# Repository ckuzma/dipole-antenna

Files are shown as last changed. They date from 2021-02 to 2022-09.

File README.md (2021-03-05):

# dipole-antenna
A 3D printed antenna for dual-band (2-meter / 70-centimeter) use.

> NOTE: This documentation is a work-in progress.  Part names, descriptions, and photographs are all subject to change.

## Description
- As designed:
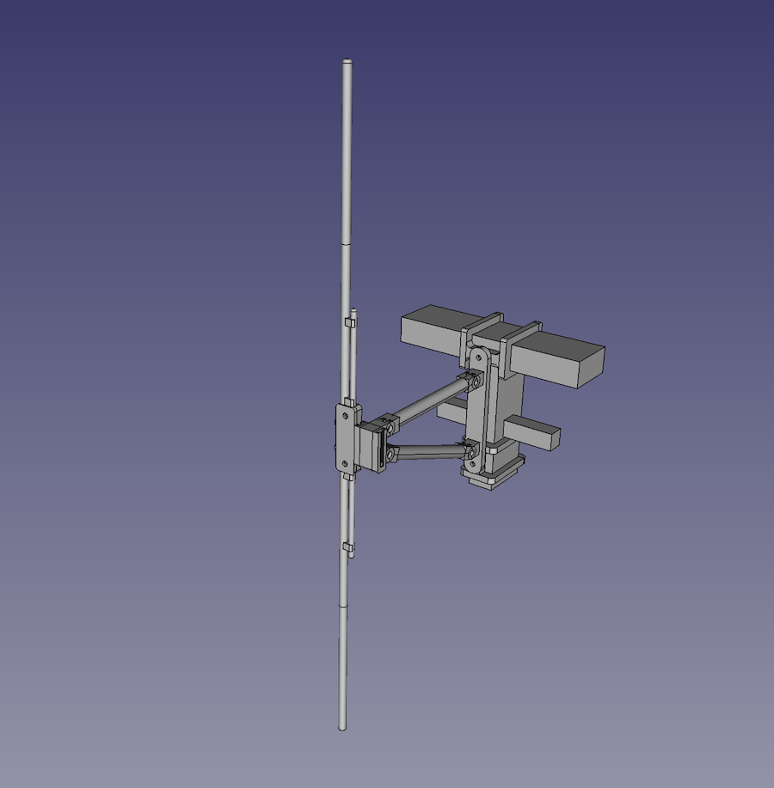
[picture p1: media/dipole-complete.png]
dipole-complete
    - 
- Reality:
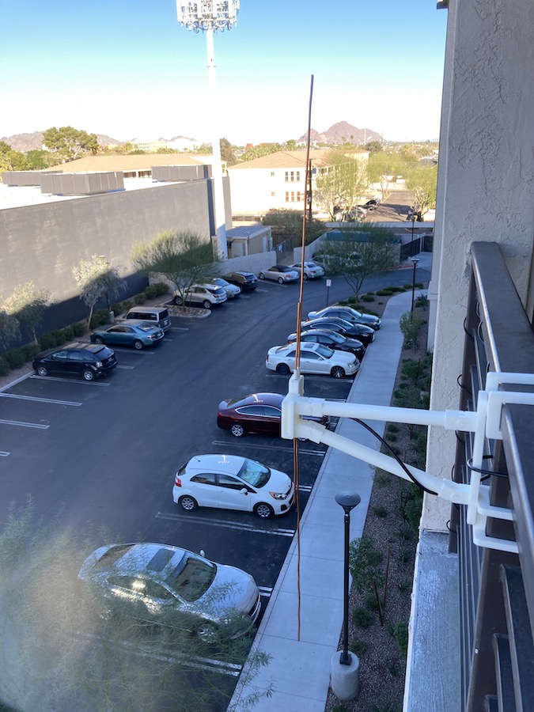
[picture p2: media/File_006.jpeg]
reality
    - 

- Details
    - SO-239 connection point
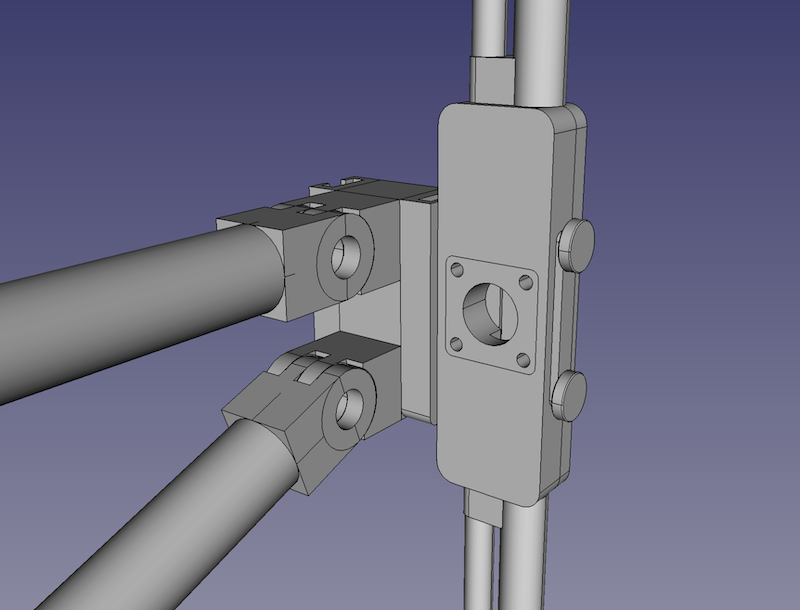
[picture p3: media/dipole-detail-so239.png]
dipole-detail-so239
        - 
    - Wall mount affixed to the railing mounts instead
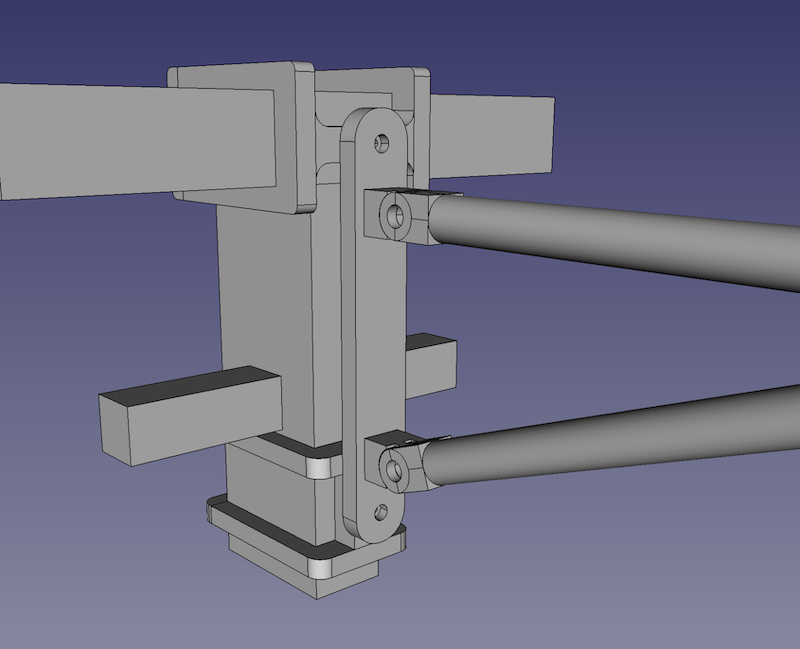
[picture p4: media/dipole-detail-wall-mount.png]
dipole-detail-wall-mount
        - 
    - Railing mounts
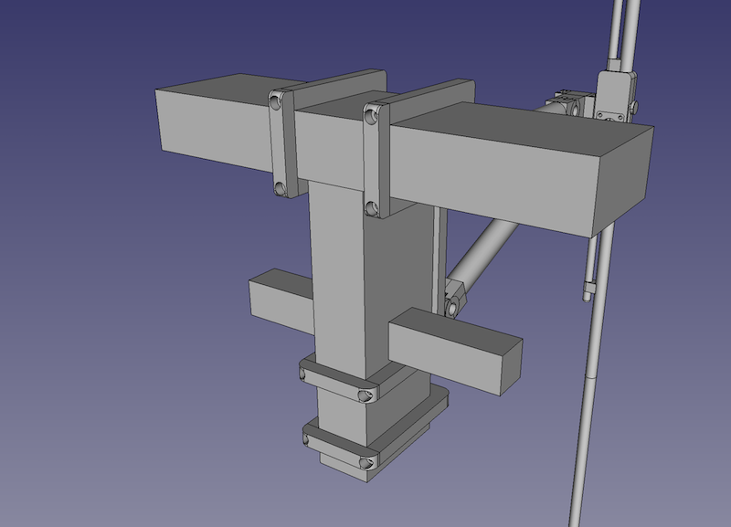
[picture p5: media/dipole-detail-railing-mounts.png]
dipole-detail-railing-mounts
        - 

## Parts
- antenna-sheath
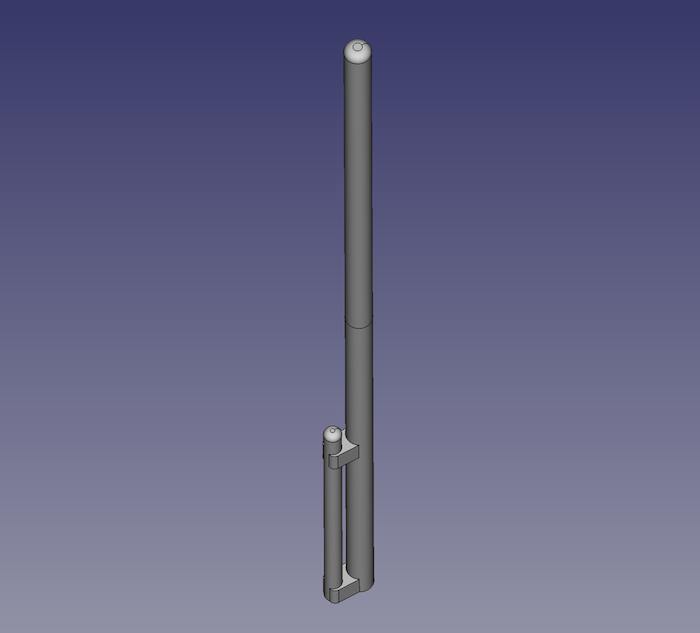
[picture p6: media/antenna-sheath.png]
antenna-sheath
    - 
    - Designed to strengthen the antenna elements as well as shield inclement weather
- holder-bottom
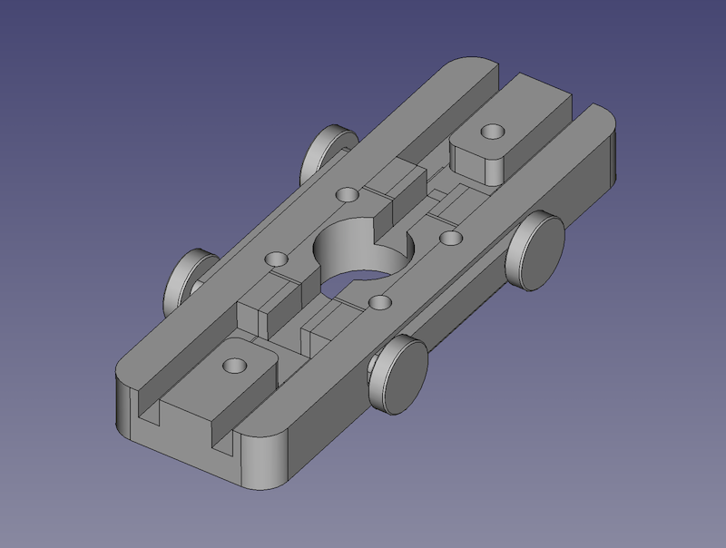
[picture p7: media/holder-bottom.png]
holder-bottom
    - 
    - Bottom section of the element holder, onto which the SO-239 connector is affixed, the antenna elements are bent, pushed, and glued into their channels, and wire leads are run from the SO-239 connector's center conductor and surrounding ground to one side each
- holder-top
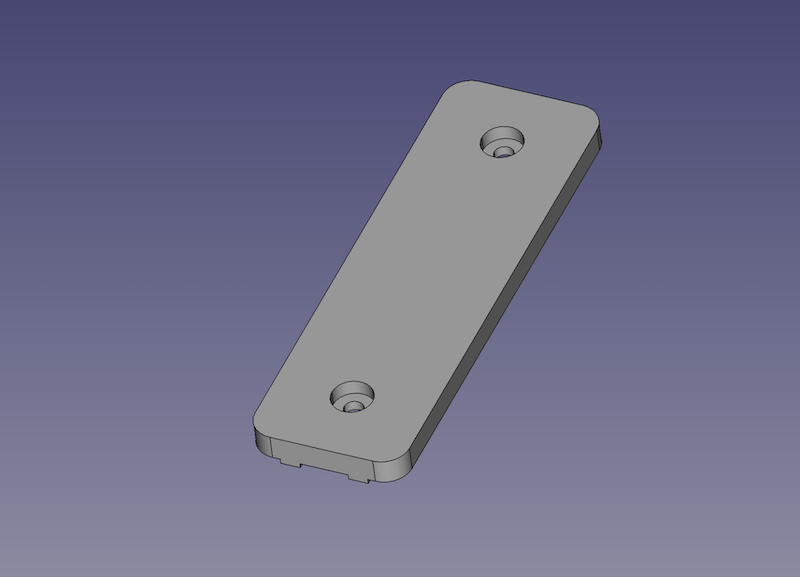
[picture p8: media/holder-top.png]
holder-top
    - 
    - Top section of the element holder whose main purpose is to keep everything held inside
- railing-adapter-upper
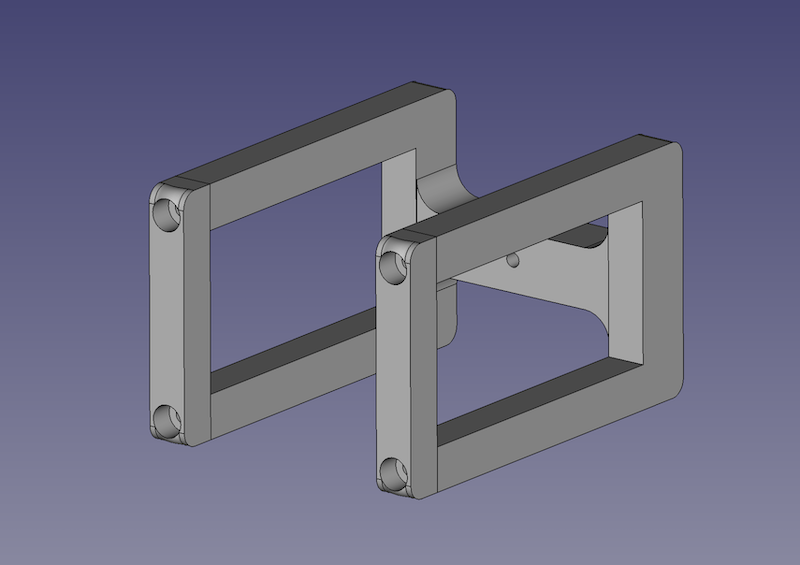
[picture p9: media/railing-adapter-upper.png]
railing-adapter-upper
    - 
    - This wraps around the horizontal handrail of my balcony's railing and has a single screw hole into which the _wall-attachment_ piece is attached
- railing-adapters-lower
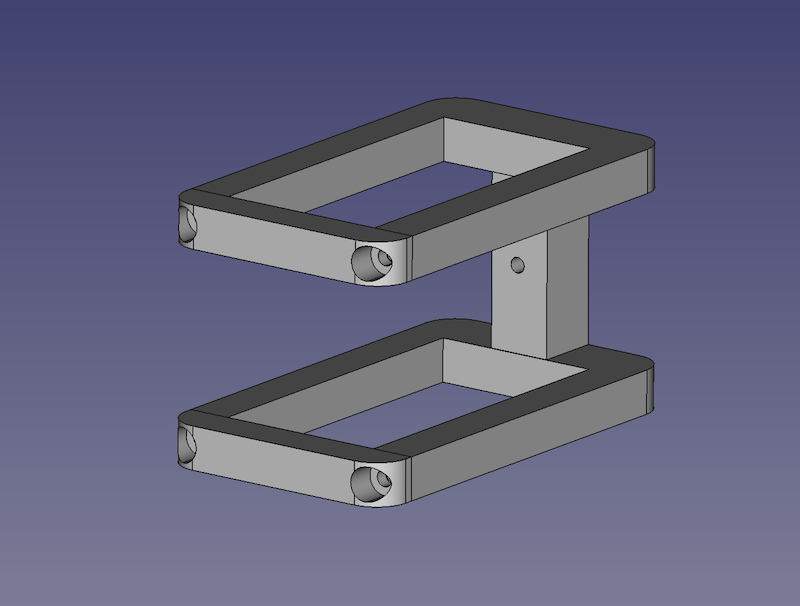
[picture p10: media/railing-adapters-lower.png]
railing-adapters-lower
    - 
    - This wraps around a vertical segment of my balcony's railing and serves to help keep the entire setup vertically oriented in addition to being an extra point to which the _wall-attachment_ piece is secured for redundancy
- completed-dipole-with-mount
    - The fullly-assembled model mounted to the railing (see above project photos)

### Components
- attachment-slot
    - Rail piece into which the dipole element holder slots into
- element-holder
    - First-pass at the main part of the structure into which the antenna elements would be press-fit
- railing
    - Mock-up of the railing off of my apartment's balcony
- so239
    - Standalone piece into which an SO-239 connector can be attached with screws

### Tests
- railing-adapter-test-fit-part
    - A thin slice of plastic to be test-fit around the balcony railing to ensure proper measurements had been made

### wall-holder
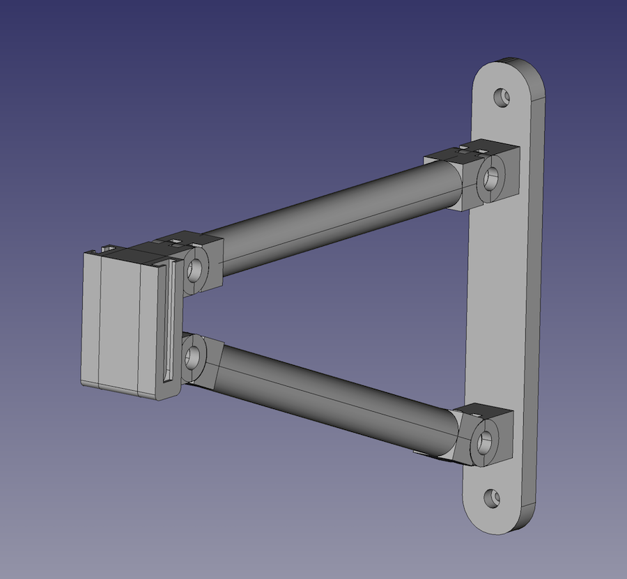
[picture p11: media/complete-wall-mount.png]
complete-wall-mount

- antenna-slot
    - The piece at the end of the arms consisting of two attachment slots
- arms
    - Two arms to connect the _wall-attachment_ piece to the _antenna-slot_ piece
- complete-attachment
    - All pieces put together (see photo above)
- pins
    - Printed pins to be used at the center of the pivots (not pictured above)
- pivots-a-b
    - Basic design of the pivots
- wall-attachment
    - The large piece mounted to an external wall to which the arms connect

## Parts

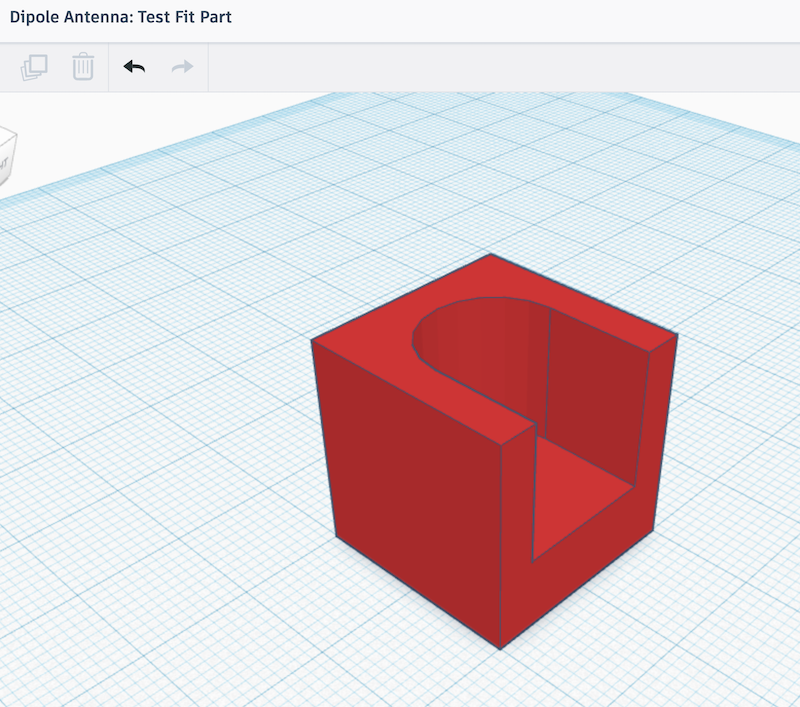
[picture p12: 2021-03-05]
media/01-element-holder-component-test-tinkercad.png

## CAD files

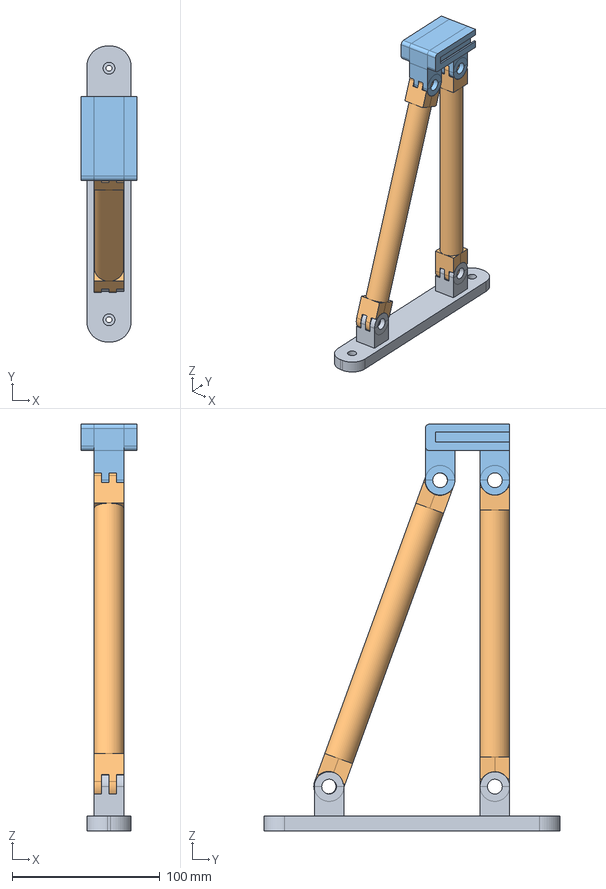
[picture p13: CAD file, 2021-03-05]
freecad_models/wall_holder/complete-attachment.FCStd
38.0 x 200.0 x 275.0 mm
Completed-Wall-Attachment
both-arms
End piece holder

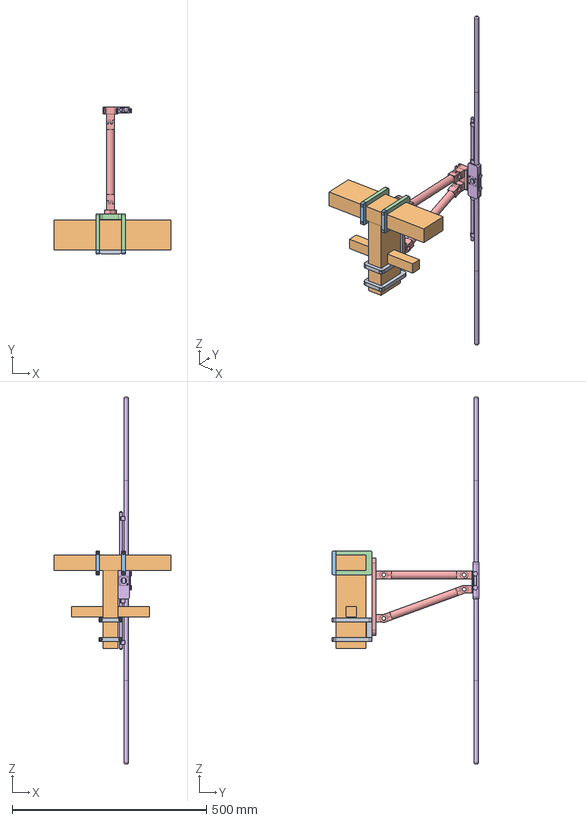
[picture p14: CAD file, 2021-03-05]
freecad_models/completed-dipole-with-mount.FCStd
300.0 x 378.0 x 945.0 mm
Rail-Grips-Lower
Simulated Railing
Rear-Pieces
Front-Wraparound
Turned-wall-mount
Dipole

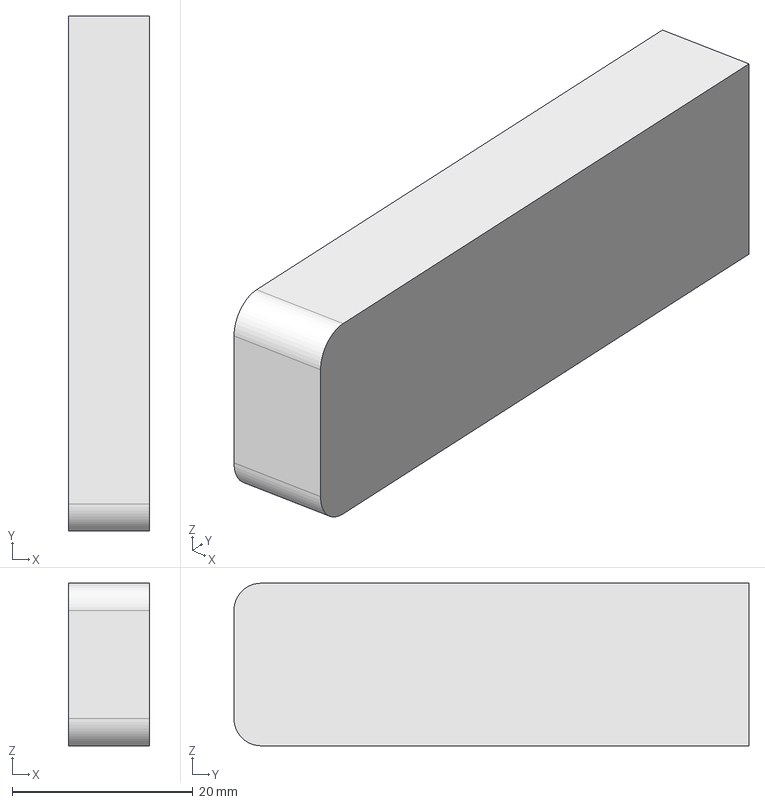
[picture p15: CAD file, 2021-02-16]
freecad_models/components/attachment-slot.FCStd
9.00 x 57.0 x 18.0 mm

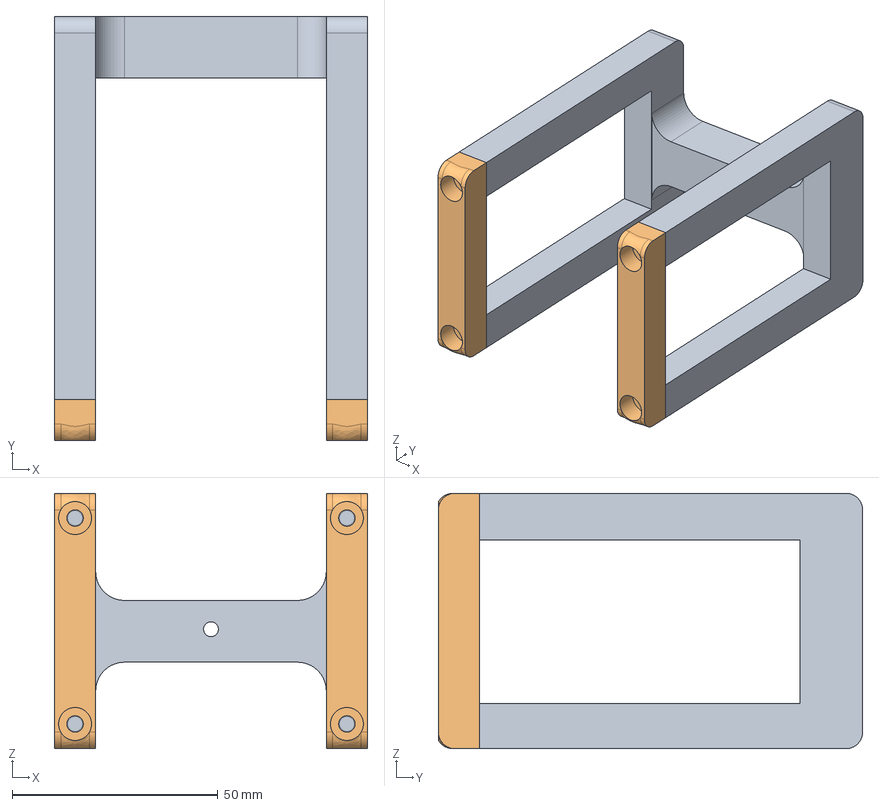
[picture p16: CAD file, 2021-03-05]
freecad_models/railing-adapter-upper.FCStd
76.0 x 103.0 x 62.0 mm
Front-Wraparound
Rear-Pieces

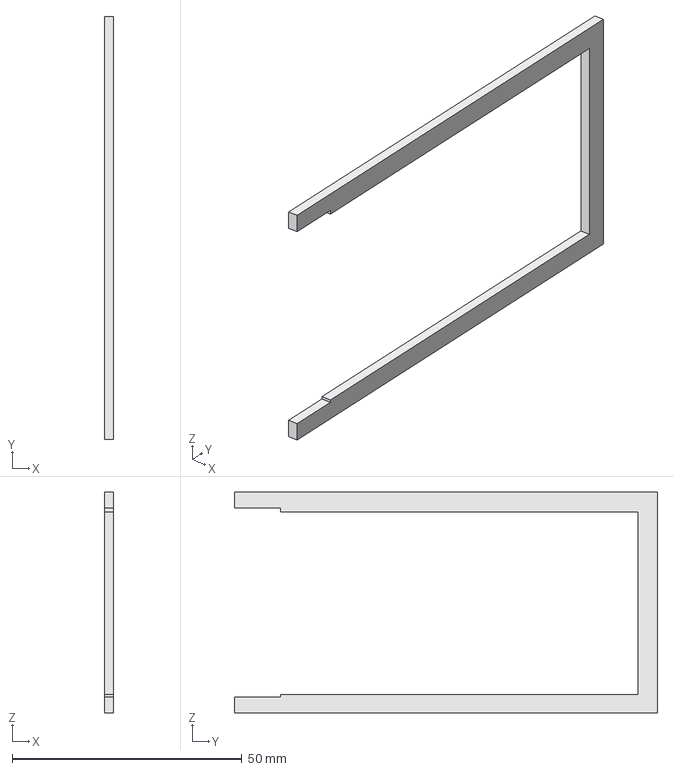
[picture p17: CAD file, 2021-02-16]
freecad_models/tests/railing-adapter-test-fit-part.FCStd
2.00 x 92.0 x 48.0 mm

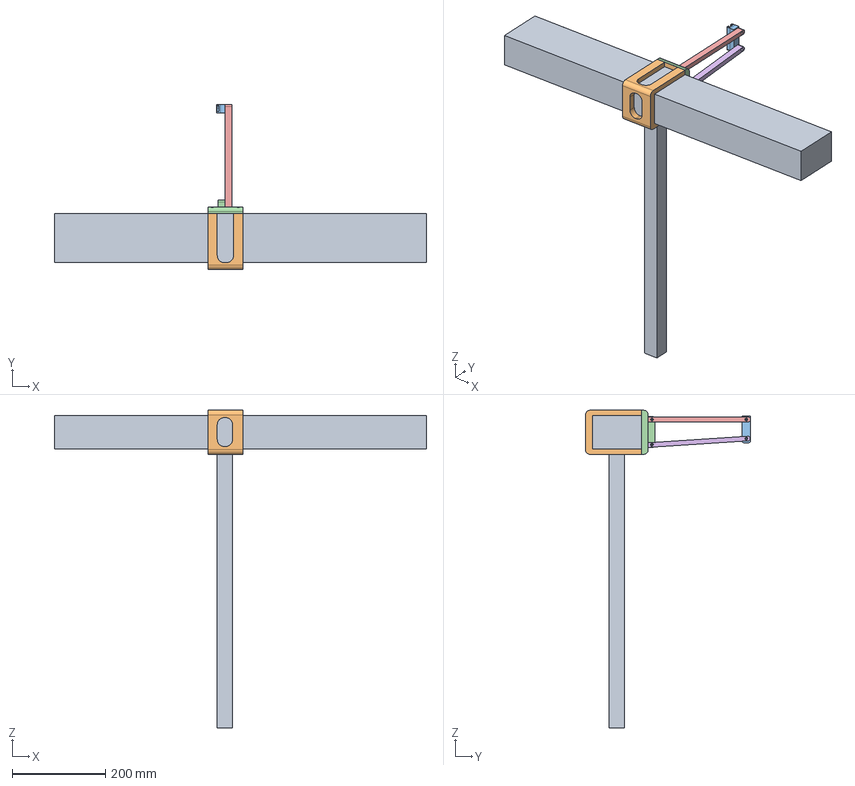
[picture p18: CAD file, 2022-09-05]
new-implementation/railing-attachment.FCStd
800.0 x 355.0 x 683.0 mm
railing-top-and-bottom
clamp-wraparound
dipole-holding-slotted-end-piece
clamp-end
rounded-top-strut-complete
rounded-bottom-strut-complete

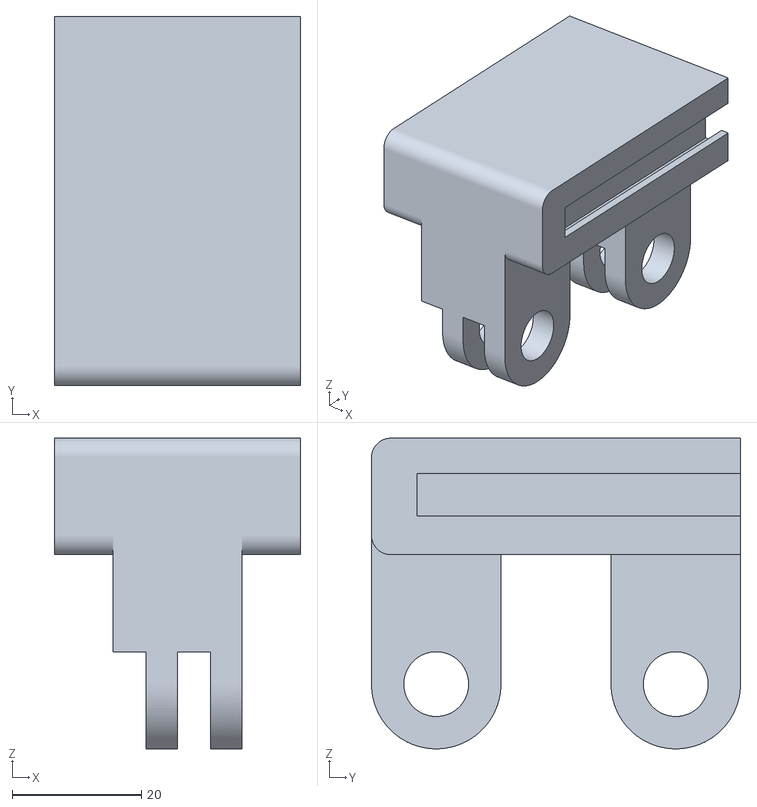
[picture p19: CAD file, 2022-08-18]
STLs/slot-bracket.stl
38.0 x 57.0 x 48.0

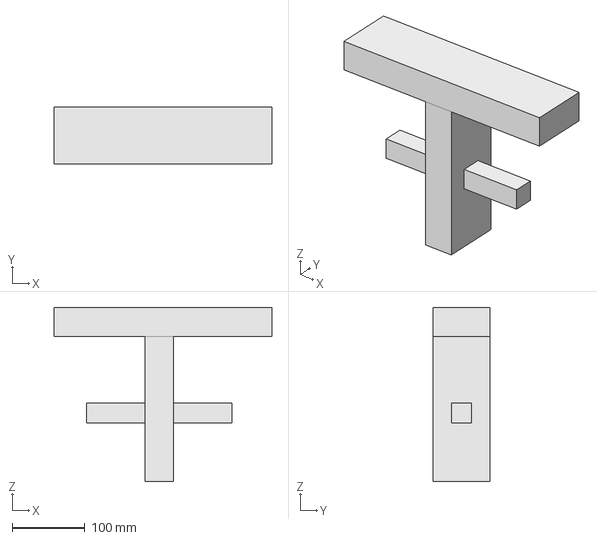
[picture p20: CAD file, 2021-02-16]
freecad_models/components/railing.FCStd
300.0 x 77.8 x 239.7 mm

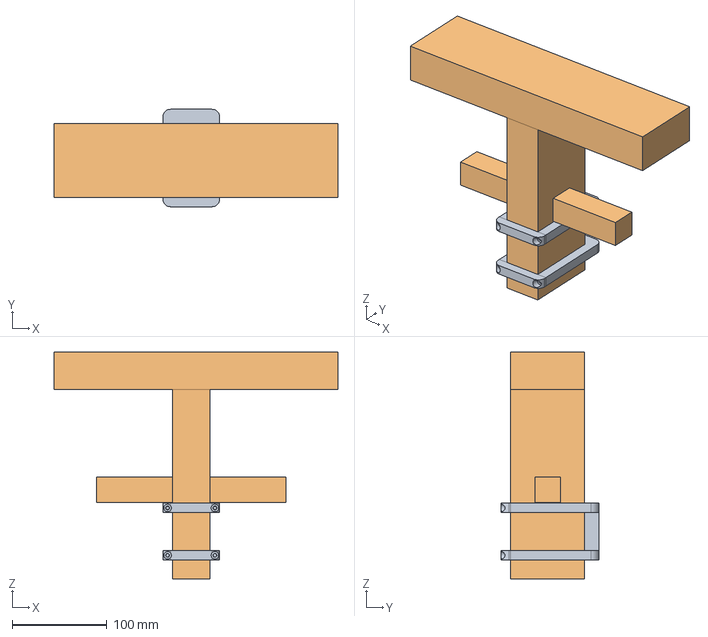
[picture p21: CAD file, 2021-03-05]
freecad_models/railing-adapters-lower.FCStd
300.0 x 103.0 x 239.7 mm
Rail-Grips-Lower
Simulated Railing

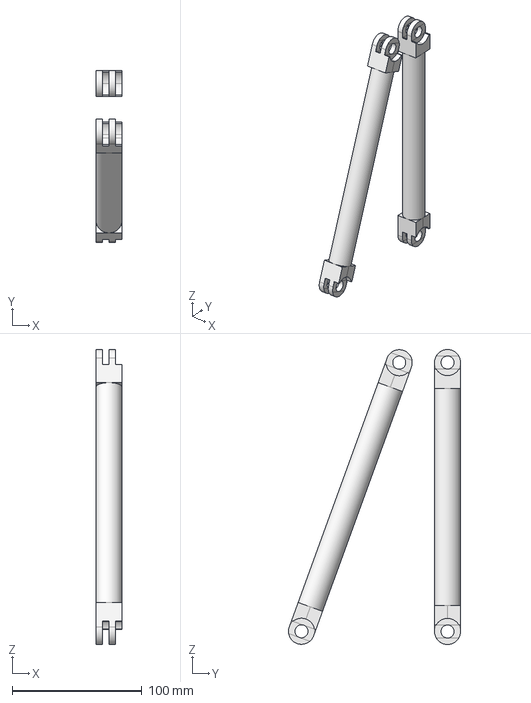
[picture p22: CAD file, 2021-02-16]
freecad_models/wall_holder/arms.FCStd
20.0 x 132.4 x 227.0 mm

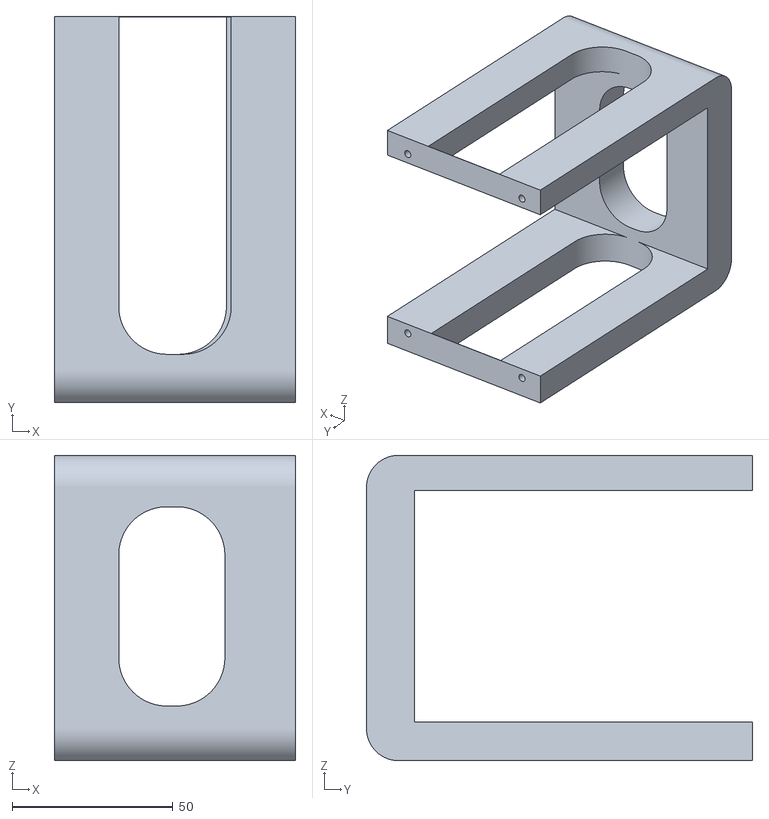
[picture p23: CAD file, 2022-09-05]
new-implementation/top-clamp-wraparound.stl
75.0 x 120.1 x 95.0

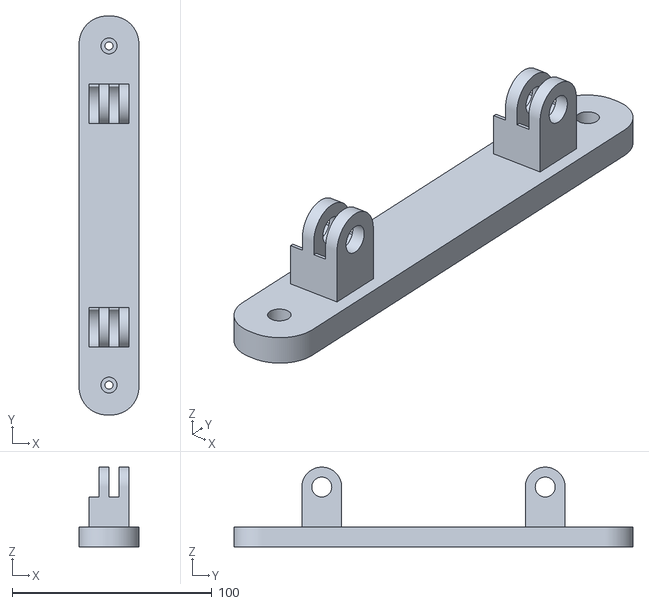
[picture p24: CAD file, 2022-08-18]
STLs/wall-bracket.stl
30.0 x 200.0 x 40.0

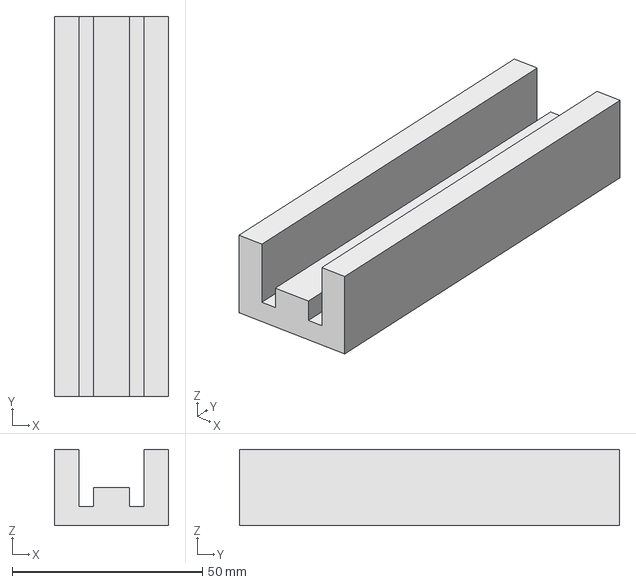
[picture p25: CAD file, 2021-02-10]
freecad_models/components/element-holder.FCStd
30.0 x 100.0 x 20.0 mm

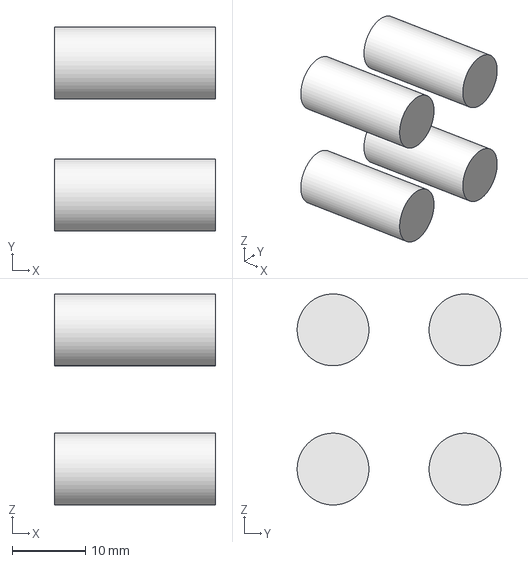
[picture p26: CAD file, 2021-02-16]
freecad_models/wall_holder/pins.FCStd
22.0 x 27.8 x 28.8 mm

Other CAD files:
new-implementation/strut-bottom.stl
STLs/extension-arms.stl
freecad_models/antenna-sheath.FCStd
freecad_models/components/so239.FCStd
STLs/holder-top.stl
freecad_models/holder-bottom.FCStd
freecad_models/holder-top.FCStd
freecad_models/wall_holder/antenna-slot.FCStd
freecad_models/wall_holder/pivots-a-b.FCStd
freecad_models/wall_holder/wall-attachment.FCStd
new-implementation/me-screw.FCStd
new-implementation/railing-mockup.FCStd
new-implementation/slotted-hub.FCStd
new-implementation/slotted-hub.stl
new-implementation/strut-top.stl
new-implementation/top-clamp-end.stl

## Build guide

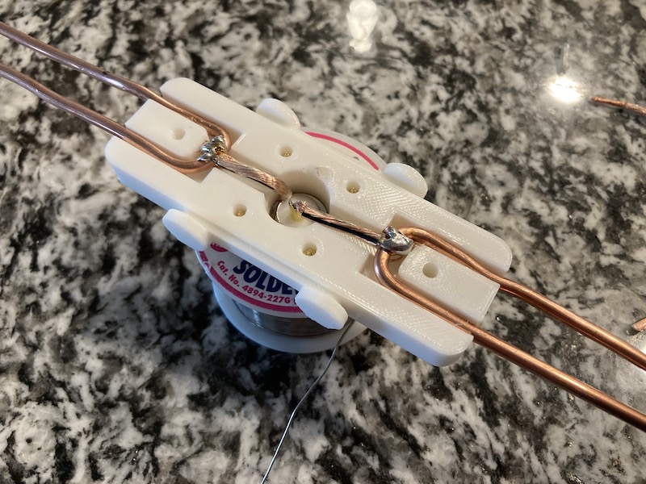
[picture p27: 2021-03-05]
media/build-documentation/File_008.jpeg

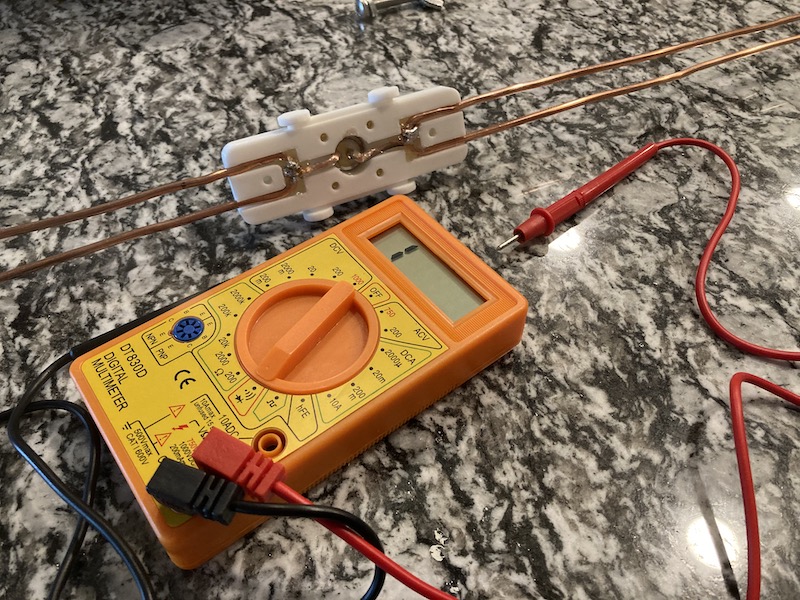
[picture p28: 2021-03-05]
media/build-documentation/File_011.jpeg

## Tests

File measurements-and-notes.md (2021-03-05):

# Measurements

## Off-the-shelf Screw
> I found this in my parts bin.

- 7.94mm diameter head of screw
- 3.97mm radius

## So for the above, this is what we're using for dimensions
1.8mm for inner threaded section
2.0mm for inner slip-through section
4.0mm for recession for screw head

## Keymod-like Attachment
- 6mm radius
- 2 mm away from holder body
- 60mm apart between nubs

Plastic pass-through hole = 5mm

## Notes
- For the wire I used, it is the equivalent of 3.6mm in diameter.  However, due to variances, 3.7mm is a better diameter to use if attempting to make something to enclose the elements.
- For my printer, I have to operate within a print size of 220x220x250mm (Creality Ender 3)

### About baluns / chokes
- "Since the goal is to eliminate common mode currents, it's much better to pass your feedline through a stack of ferrite cores (no coils). When I was having isolation issues on a UHF dipole I made, I found that about 5 clamp-ons made the difference."
    - https://www.reddit.com/r/amateurradio/comments/kzafp4/fancy_horizontal_dipole_for_2m_ssb/gjmoys1/
- "You'll probably be fine, but coax baluns can be pretty narrow band depending on the characteristics of the antenna and feed line. If you have any trouble with RF in the shack, a clip on ferrite bead on either side of the balun should fix you right up, as those beads are quite effective on VHF and UHF (much less so on HF, bead baluns suck below 50MHz)."
    - https://www.reddit.com/r/amateurradio/comments/fqymd9/2m70cm_vertical_dipole_antenna_just_waiting_for/

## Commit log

2021-02-05 Added SO-239 mounting point
    [so239.FCStd, so239.stl]
2021-02-05 Added element holder, incomplete
    [element-holder.FCStd, element-holder.stl]
2021-02-05 First attempt at holder complete
    [dipole-combo.FCStd, dipole-combo.stl]
2021-02-09 Adding earlier versioning for posterity
    [Dipole Antenna_ Element Sheath Test-2.stl, Dipole Antenna_ Socket Block.stl, Dipole Antenna_ Static Mk 1.stl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]
2021-02-09 Created new test print for final dipole, fixed redundancies in specifications
    [dipole-combo2-test-print.FCStd, dipole-combo2.FCStd, element-holder.FCStd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]
2021-02-10 Cleaned up repo
    [Dipole Antenna_ Element Sheath Test-2.stl, Dipole Antenna_ Socket Block.stl, Dipole Antenna_ Static Mk 1.stl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]
2021-02-10 Added another try at the wall-mount
    [wall-mount-unfinished.FCStd]
2021-02-11 Resized test for wall mount (still not there yet) and added relief cuts to lid for holder
    [holder-top.FCStd, wall-mount-unfinished.FCStd]
2021-02-11 Tweaked wall mount by 0.4mm smaller for cutouts
    [wall-mount-unfinished.FCStd]
2021-02-16 Finished modeling the railing based off of measurements
    [railing.FCStd]
2021-02-16 Just need to add holders
    [railing-mount.FCStd, railing.FCStd]
2021-02-16 First go at mount, but requires rework to fit
    [attachment-slot.FCStd, railing-mount.FCStd, railing.FCStd]
2021-02-16 Had to change sizes and design to fit print bed, need to rethink but want to try this anyway
    [railing-mount.FCStd]
2021-02-16 Test fit for railing mount
    [attachment-slot.FCStd, railing-mount-v2.FCStd]
2021-02-16 Work on wall mount
    [antenna-slot.FCStd, arms.FCStd, pins.FCStd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]
2021-02-16 Hopefully got this right, time to start printing
    [arms.FCStd, pins.FCStd]
2021-02-18 Updated measurements, created railing grips, ready to test print
    [wall-mount-rail-grippers.FCStd, wall-mount-to-railing-adapters.FCStd]
2021-02-18 Small error in placement, fixed
    [wall-mount-rail-grippers.FCStd, wall-mount-to-railing-adapters.FCStd]
2021-02-18 Worked on antenna sheath
    [antenna-sheath.FCStd]
2021-02-18 TODO: Top rail clamp make larger
    [wall-mount-to-railing-adapters.FCStd]
2021-03-05 Pushing media and some initial documentation, other photos missing
    [complete-attachment.FCStd, completed-dipole-with-mount.FCStd, railing-adapter-test-fit-part.FCStd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]
2022-08-18 Added new slotted hub design
    [slotted-hub.FCStd, slotted-hub.stl]
2022-08-18 Updated STLs
    [extension-arms.stl, holder-top.stl, slot-bracket.stl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]
2022-08-23 Modeled top clamp and started printing top wraparound to test fit
    [railing-attachment.FCStd, railing-mockup.FCStd, top-clamp-wraparound.stl]
2022-08-23 Fixed slotted ub
    [railing-attachment.FCStd, slotted-hub.FCStd]
2022-08-23 Finished the rest of the mount
    [me-screw.FCStd, railing-attachment.FCStd, slotted-hub.FCStd]
2022-08-23 Split upper and lower struts for printing, put files somewhere convenient
    [railing-attachment.FCStd, strut-bottom.stl, strut-top.stl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]
2022-09-05 Added new clamp wraparound with extra room for fitting
    [railing-attachment.FCStd, top-clamp-wraparound.stl]
